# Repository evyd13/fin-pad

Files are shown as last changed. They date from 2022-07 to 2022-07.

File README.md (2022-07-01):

# Fin Pad

Replacement PCB for Lin Dolphin Pad.

Fin Pad PCB

## License

Read the license before use!

## Gerbers

Gerber zip files can be found under `gerber/`.

## BOM

| LCSC part # | Description | Value | Package  | Amount |
| --- | --- | ----- | --- | ---:|
| C14663 | Capacitor | 0.1uF | 0603 | 3 |
| C19666 | Capacitor | 4.7uF | 0603 | 1 |
| C15849 | Capacitor | 1uF | 0603 | 1 |
| C2128 | Switch diode  | 4148  | 0805 | 24 |
| C261942 | Fuse | | 0805 | 1 |
| C165948 | Type-C con. | | SMD+TH | 1 |
| C25804 | Resistor | 10K | 0603 | 2 |
| C23345 | Resistor | 22 | 0603 | 2 |
| C23186 | Resistor | 5.1k  | 0603 | 2 |
| C7519 | ESD prot. | | SOT23-6  | 1 |
| C1337609 | MCU | 32U2  | QFP-32 | 1 |
| C341521 | Resonator | 16MHz | SMD | 1 |
| C92584 | Switch | | SMD | 1 |

Use at your own risk.

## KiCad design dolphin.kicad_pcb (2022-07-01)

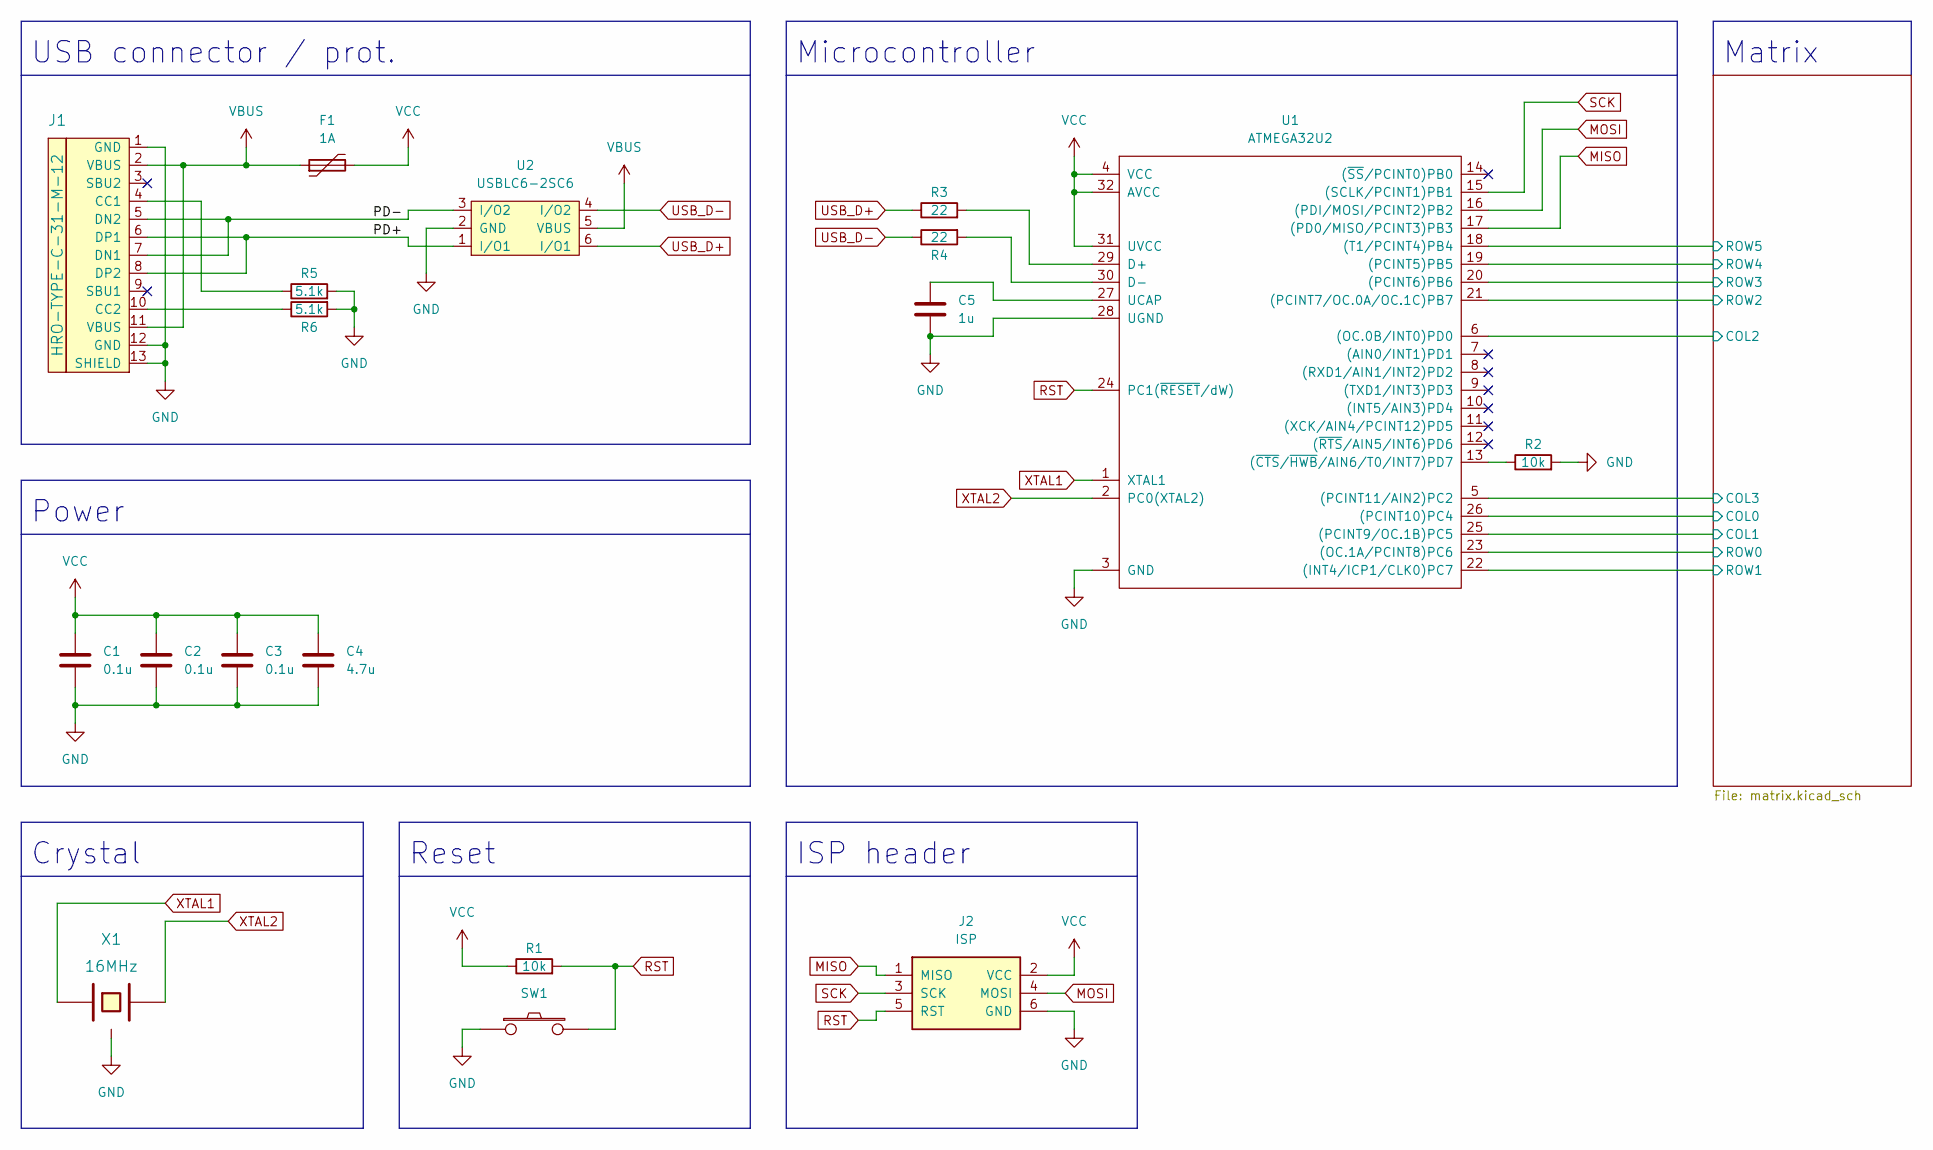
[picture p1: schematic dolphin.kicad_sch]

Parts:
C1, C2, C3: 0.1u; C_0603; Part number CC0603KRX7R9BB104; LCSC Part C14663
C4: 4.7u; C_0603; Part number CL10A475KO8NNNC; LCSC Part C19666
C5: 1u; C_0603; Part number CL10A105KB8NNNC; LCSC Part C15849
F1: 1A; R_0805; Part number TLC-PSMD050; LCSC Part C261942
J1: HRO-TYPE-C-31-M-12; CONN_HRO-TYPE-C-31-M-12; Part number TYPE-C-31-M-12; LCSC Part C165948
J2: ISP; CONN_isp_standard; JLCPCB BOM 0
R1, R2: 10k; R_0603; Part number 0603WAF1002T5E; LCSC Part C25804
R3, R4: 22; R_0603; Part number 0603WAF220JT5E; LCSC Part C23345
R5, R6: 5.1k; R_0603; Part number 0603WAF5101T5E; LCSC Part C23186
SW1: SW_PUSH; SWITCH_SPST_TL3342; Part number TS-1187A-B-A-B; LCSC Part C318884
U1: ATMEGA32U2; MCU_ATMEGA32U2-AU
U2: USBLC6-2SC6; PACKAGE_SOT-23-6; Part number USBLC6-2SC6; LCSC Part C7519
X1: 16MHz; XTAL_SMD_Murata_CSTxExxV-3Pin_3.0x1.1mm; Part number CSTNE16M0V530000R0; LCSC Part C341521

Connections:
/Matrix/COL0: U1.26 ((PCINT10)PC4); also elsewhere on the board
/Matrix/COL1: U1.25 ((PCINT9/OC.1B)PC5); also elsewhere on the board
/Matrix/COL2: U1.6 ((OC.0B/INT0)PD0); also elsewhere on the board
/Matrix/COL3: U1.5 ((PCINT11/AIN2)PC2); also elsewhere on the board
/Matrix/ROW0: U1.23 ((OC.1A/PCINT8)PC6); also elsewhere on the board
/Matrix/ROW1: U1.22 ((INT4/ICP1/CLK0)PC7); also elsewhere on the board
/Matrix/ROW2: U1.21 ((PCINT7/OC.0A/OC.1C)PB7); also elsewhere on the board
/Matrix/ROW3: U1.20 ((PCINT6)PB6); also elsewhere on the board
/Matrix/ROW4: U1.19 ((PCINT5)PB5); also elsewhere on the board
/Matrix/ROW5: U1.18 ((T1/PCINT4)PB4); also elsewhere on the board
/PD+: J1.6 (DP1), J1.8 (DP2), U2.1 (I/O1)
/PD-: J1.5 (DN2), J1.7 (DN1), U2.3 (I/O2)
GND: C1.2, C2.2, C3.2, C4.2, C5.2, J1.1 (GND), J1.12 (GND), J1.13 (SHIELD), J2.6 (GND), R2.2, R5.2, R6.2, SW1.1, U1.3 (GND), U1.28 (UGND), U2.2 (GND), X1.3
MISO: J2.1 (MISO), U1.17 ((PD0/MISO/PCINT3)PB3)
MOSI: J2.4 (MOSI), U1.16 ((PDI/MOSI/PCINT2)PB2)
unnamed: C5.1, U1.27 (UCAP)
unnamed: J1.4 (CC1), R5.1
unnamed: J1.10 (CC2), R6.1
unnamed: R2.1, U1.13 ((~CTS/~HWB/AIN6/T0/INT7)PD7)
unnamed: R3.2, U1.29 (D+)
unnamed: R4.2, U1.30 (D-)
RST: J2.5 (RST), R1.2, SW1.2, U1.24 (PC1(~RESET/dW))
SCK: J2.3 (SCK), U1.15 ((SCLK/PCINT1)PB1)
USB_D+: R3.1, U2.6 (I/O1)
USB_D-: R4.1, U2.4 (I/O2)
VBUS: F1.1, J1.2 (VBUS), J1.11 (VBUS), U2.5 (VBUS)
VCC: C1.1, C2.1, C3.1, C4.1, F1.2, J2.2 (VCC), R1.1, U1.4 (VCC), U1.31 (UVCC), U1.32 (AVCC)
XTAL1: U1.1 (XTAL1), X1.1
XTAL2: U1.2 (PC0(XTAL2)), X1.2

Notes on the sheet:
Matrix
Microcontroller
Power
Reset
ISP header
Crystal
USB connector / prot.

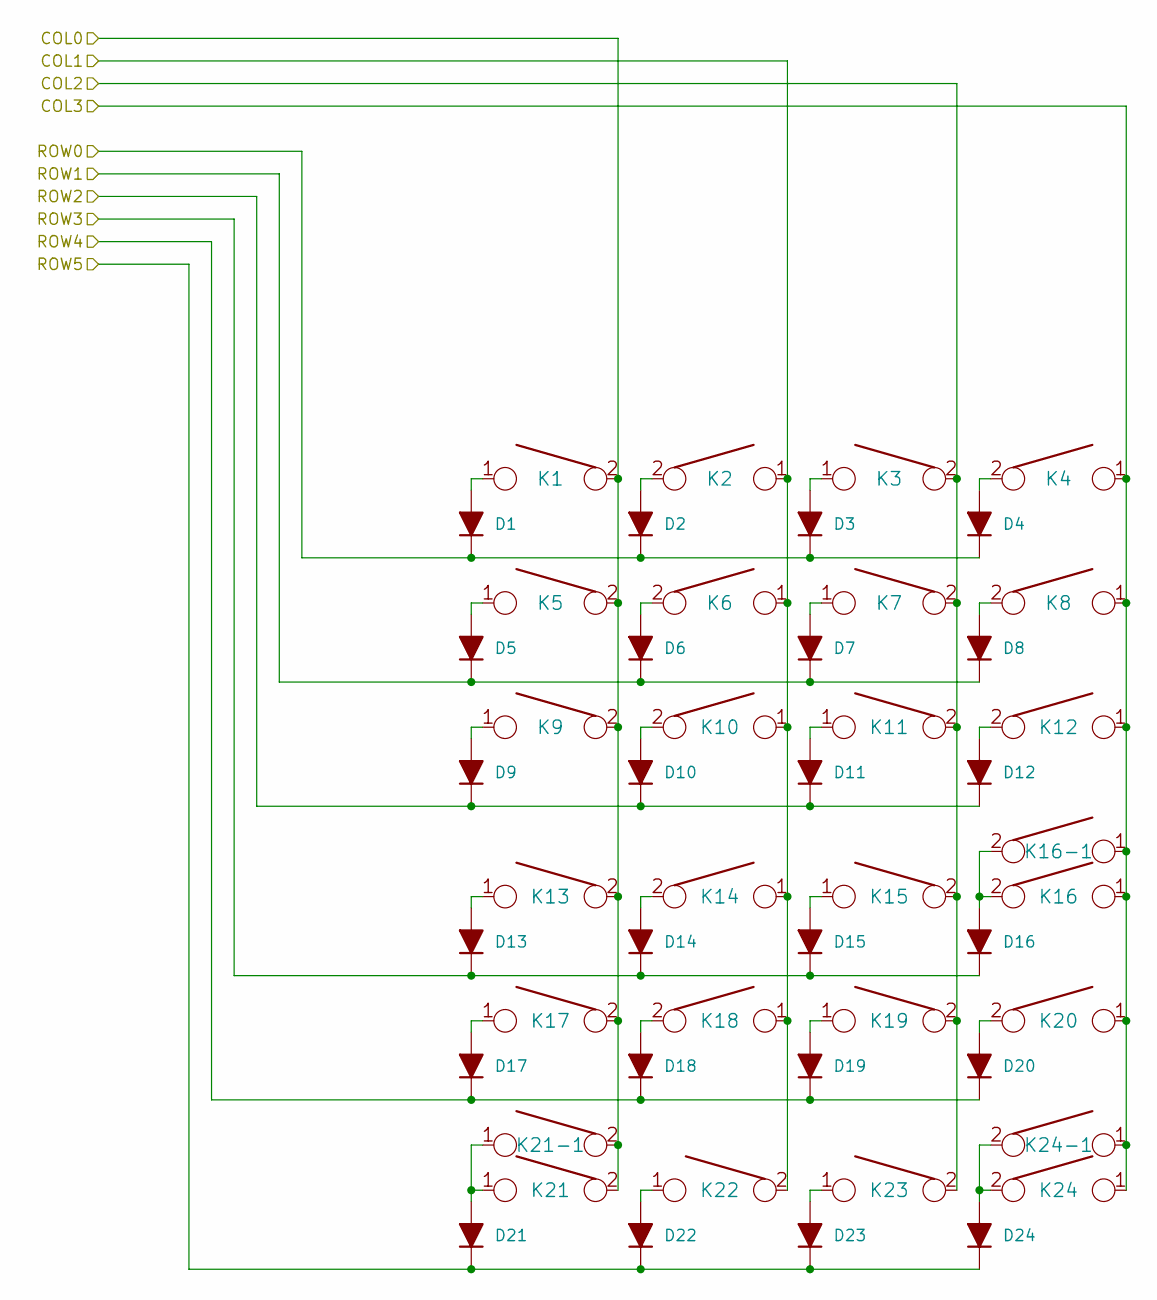
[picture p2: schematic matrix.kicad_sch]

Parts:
D1, D2, D3, D4, D5, D6, D7, D8, D9, D10, D11, D12, D13, D14, D15, D16, D17, D18, D19, D20, D21, D22, D23, D24: 4148; D_0805; Part number 1N4148WS; LCSC Part C2128
K1, K2, K3, K4, K5, K6, K7, K8, K9, K10, K11, K12, K13, K14, K15, K16, K17, K18, K19, K20, K21, K22, K23, K24: KEYSW; CHERRY_PLATE_100H; JLCPCB BOM 0
K16-1, K24-1: KEYSW; CHERRY_PCB_200H_V; JLCPCB BOM 0
K21-1: KEYSW; CHERRY_PCB_200H_F; JLCPCB BOM 0

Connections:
/Matrix/COL0: K1.2, K5.2, K9.2, K13.2, K17.2, K21.2, K21-1.2; also elsewhere on the board
/Matrix/COL1: K2.1, K6.1, K10.1, K14.1, K18.1, K22.2; also elsewhere on the board
/Matrix/COL2: K3.2, K7.2, K11.2, K15.2, K19.2, K23.2; also elsewhere on the board
/Matrix/COL3: K4.1, K8.1, K12.1, K16.1, K16-1.1, K20.1, K24.1, K24-1.1; also elsewhere on the board
/Matrix/ROW0: D1.1 (K), D2.1 (K), D3.1 (K), D4.1 (K); also elsewhere on the board
/Matrix/ROW1: D5.1 (K), D6.1 (K), D7.1 (K), D8.1 (K); also elsewhere on the board
/Matrix/ROW2: D9.1 (K), D10.1 (K), D11.1 (K), D12.1 (K); also elsewhere on the board
/Matrix/ROW3: D13.1 (K), D14.1 (K), D15.1 (K), D16.1 (K); also elsewhere on the board
/Matrix/ROW4: D17.1 (K), D18.1 (K), D19.1 (K), D20.1 (K); also elsewhere on the board
/Matrix/ROW5: D21.1 (K), D22.1 (K), D23.1 (K), D24.1 (K); also elsewhere on the board
unnamed: D1.2 (A), K1.1
unnamed: D2.2 (A), K2.2
unnamed: D3.2 (A), K3.1
unnamed: D4.2 (A), K4.2
unnamed: D5.2 (A), K5.1
unnamed: D6.2 (A), K6.2
unnamed: D7.2 (A), K7.1
unnamed: D8.2 (A), K8.2
unnamed: D9.2 (A), K9.1
unnamed: D10.2 (A), K10.2
unnamed: D11.2 (A), K11.1
unnamed: D12.2 (A), K12.2
unnamed: D13.2 (A), K13.1
unnamed: D14.2 (A), K14.2
unnamed: D15.2 (A), K15.1
unnamed: D16.2 (A), K16.2, K16-1.2
unnamed: D17.2 (A), K17.1
unnamed: D18.2 (A), K18.2
unnamed: D19.2 (A), K19.1
unnamed: D20.2 (A), K20.2
unnamed: D21.2 (A), K21.1, K21-1.1
unnamed: D22.2 (A), K22.1
unnamed: D23.2 (A), K23.1
unnamed: D24.2 (A), K24.2, K24-1.2

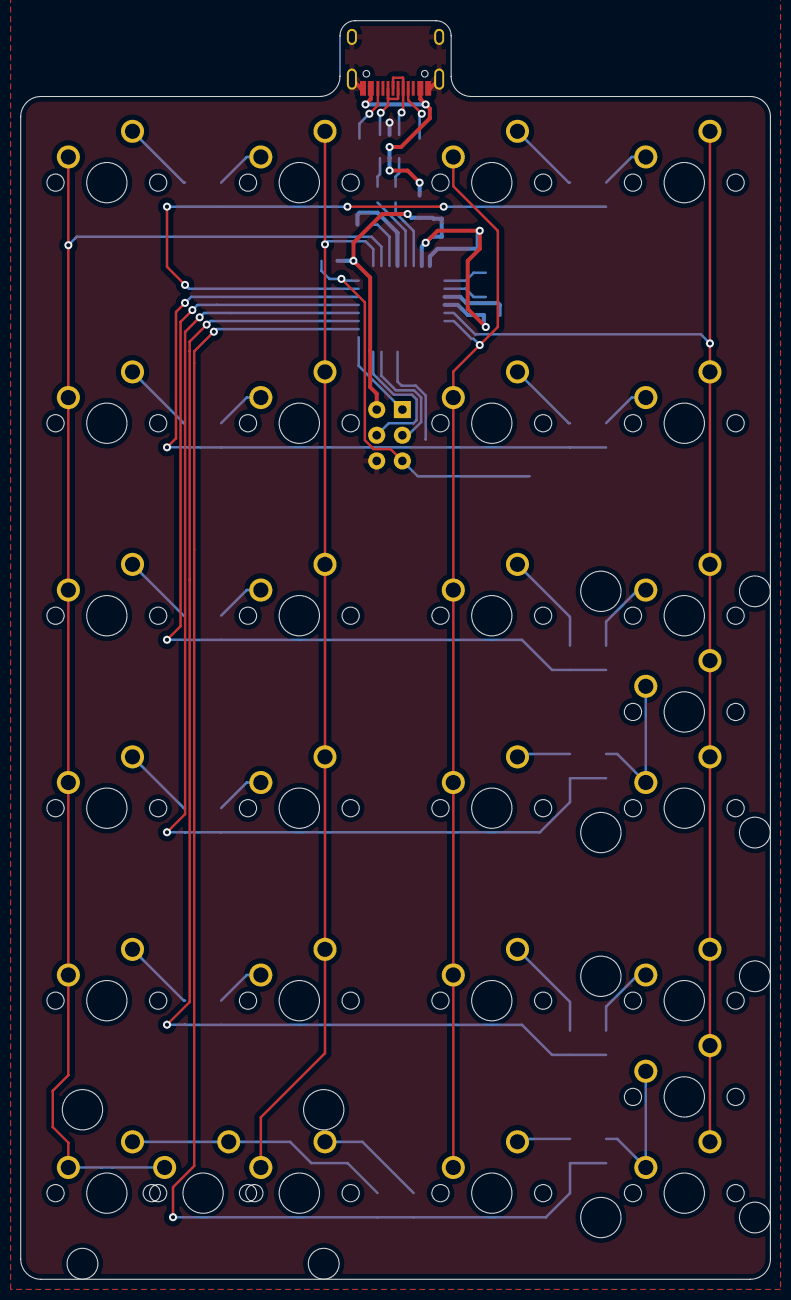
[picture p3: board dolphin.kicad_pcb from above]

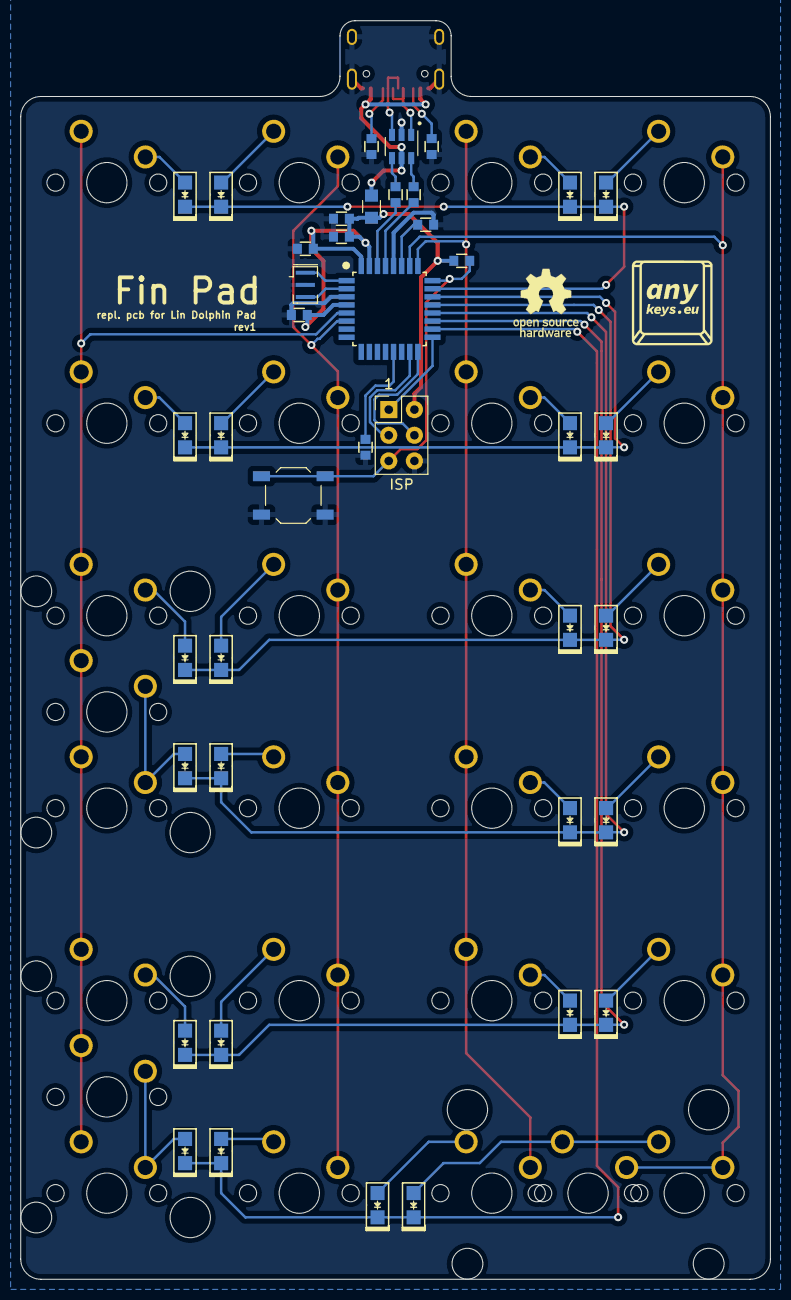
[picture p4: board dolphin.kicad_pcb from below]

Board: 2 copper layers, 74.2 x 124.6 mm, 69 parts (41 on the bottom side), 53 nets.

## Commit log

2022-07-01 Upload rev1 files
    [dolphin.kicad_pcb, dolphin.kicad_sch, matrix.kicad_sch]
2022-07-01 Add BOM/readme
    [dolphin.kicad_sch]
2022-07-01 Add gerber
